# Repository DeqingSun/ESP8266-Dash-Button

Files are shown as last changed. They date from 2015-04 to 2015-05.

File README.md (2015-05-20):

# ESP8266 Dash Button

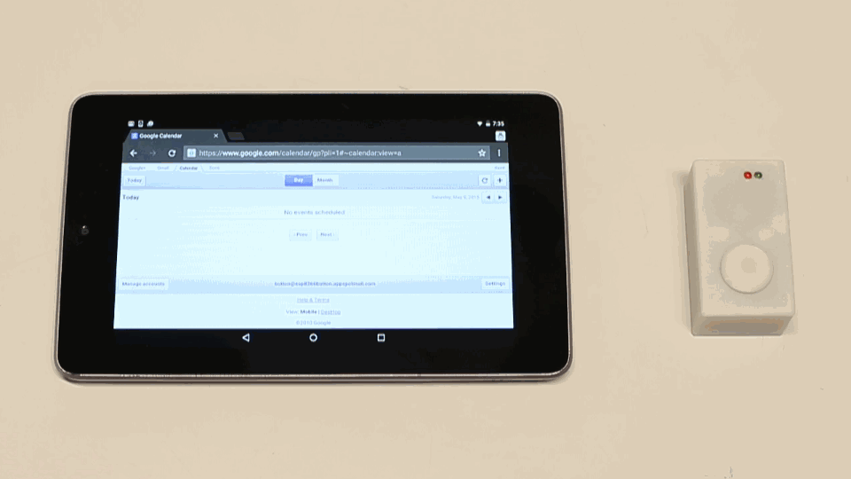
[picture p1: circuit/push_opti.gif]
full


This is a small box with only one button. Every time you push the button. It will connect to WiFi and access an URL.

WiFi SSID and Password can be configured through ESP-TOUCH protocol and the URL can be changed by UDP packet. Two LEDs on it's case shows status of module and circuit.

## Internal Structure

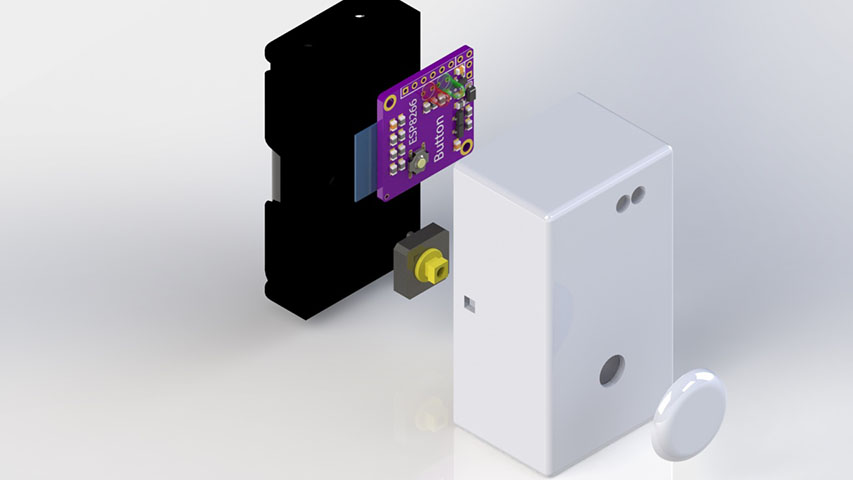
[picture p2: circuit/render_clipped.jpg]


This button consists of following parts: Two AA batteries and battery holder, ESP8266 module and circuit, a big button for better experience, case, button cover. 

## How it works

When button is pressed, the circuit powers ESP8266 module and the module will connect to WiFi with SSID and password in flash memory. Once Wifi connection is established, this button will request a certain URL in flash memory and turn itself off to save power.

## How to config WiFi network and URL

There is an minimal Android app in this repo that can do configuration wirelessly.

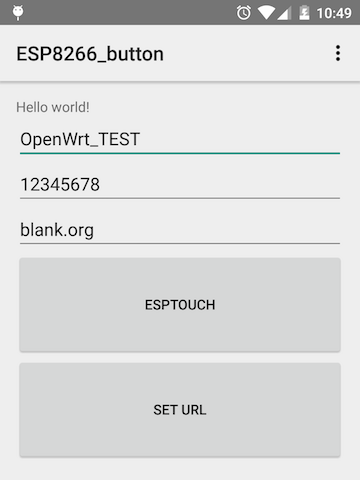
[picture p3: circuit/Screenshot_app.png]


The app is a barely working one and it lacks advanced features for now. However it does work. You can hold button on ESP8266 board for 5 seconds and it will enter ESP-TOUCH mode. The Android code is a bit messy because they are decompiled from a obfuscated APK file. 

You can connect your phone to target WiFi network, fill textbox with SSID and password and press "ESPTouch", then the app will encode SSID and password in length of UDP packets and broadcast packets to all devices. If ESP8266 decodes WiFi information successfully, it will broadcast a UDP packet back to your phone to end pairing process and listen UDP packets for URL. You can enter URL into third textbox and press "SET URL" to finish setting process.

If you want to change the URL only, press button once when it is in ESP-Touch mode.

## How to make one

You can use the gerber files in this repo or you can order PCB with [OSH Park](https://oshpark.com/shared_projects/X8mGIjUE) directly.

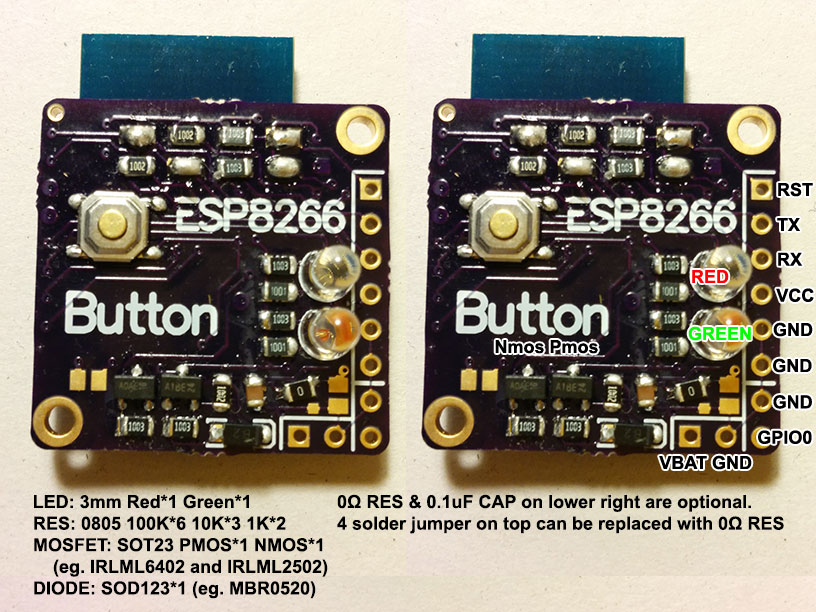
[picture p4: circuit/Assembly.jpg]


After you solder all parts and ESP-12 module, you can either compile the source code on your own or use the pre-compiled bin files. 

## How to do more things with IFTTT

Currently IFTTT can not be triggered with a HTTP request. So I created a App Engine app to send a Email to IFTTT. The app can print all email it received in log file so you can create account with App Engine Email Address.

Here is an example of add Google Calendar entry with button.

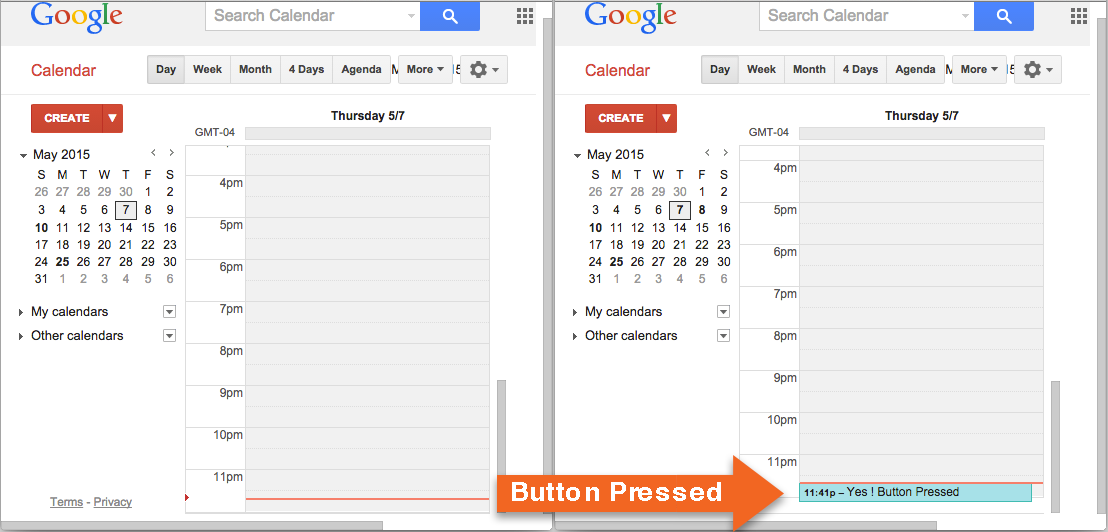
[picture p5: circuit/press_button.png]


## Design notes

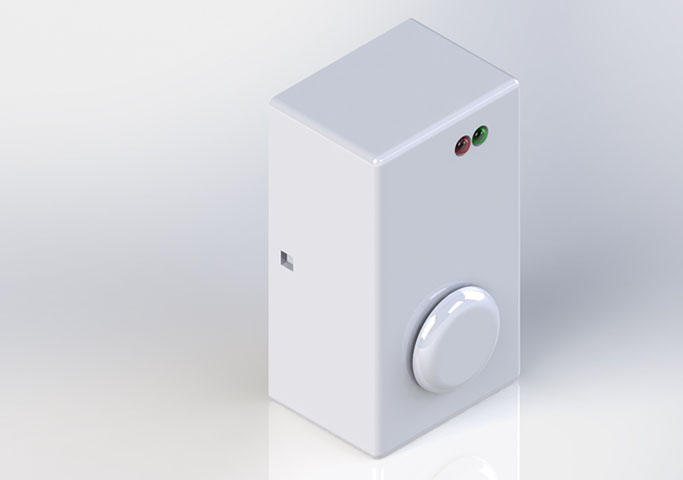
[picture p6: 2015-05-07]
circuit/render_full_clipped.jpg

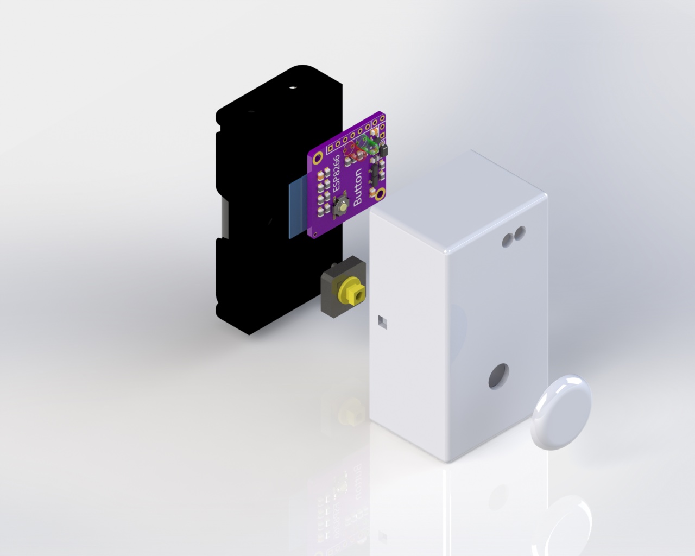
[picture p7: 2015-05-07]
circuit/render.jpg

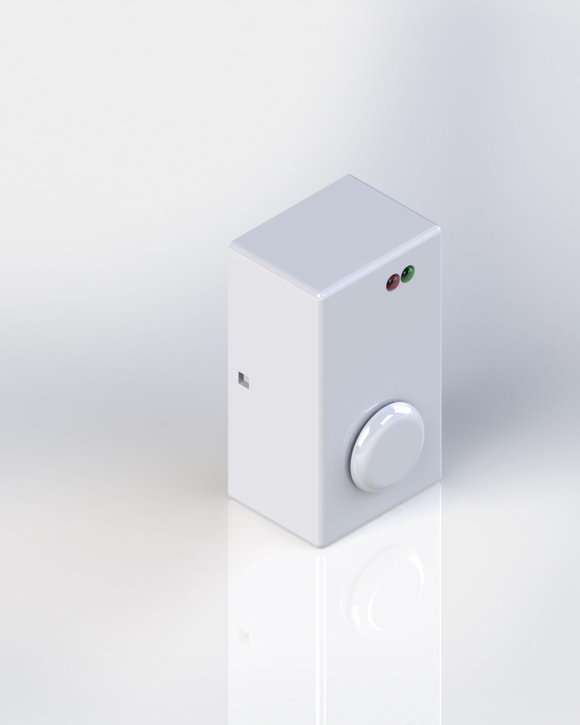
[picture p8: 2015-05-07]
circuit/render_full.jpg

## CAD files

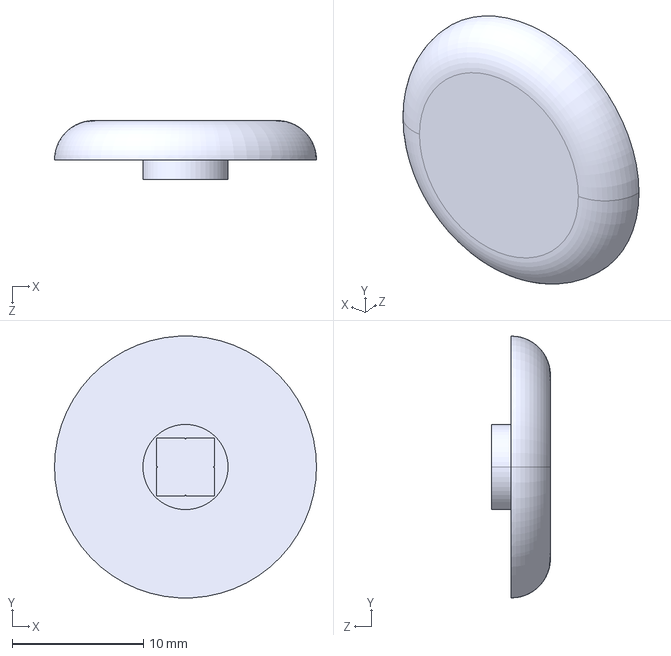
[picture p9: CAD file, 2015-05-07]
circuit/step/button_cap.STEP
20.0 x 20.0 x 4.50 mm

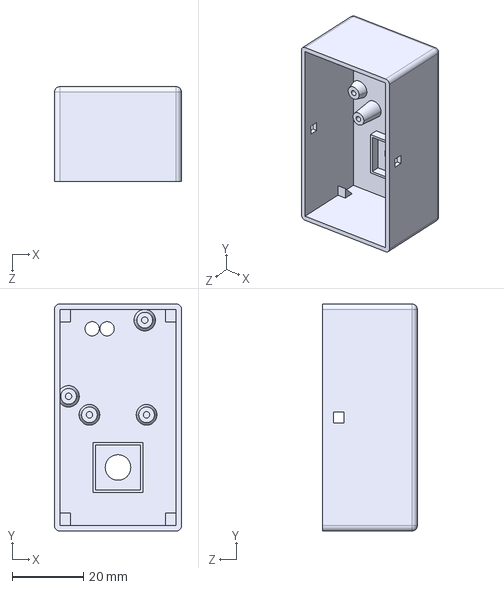
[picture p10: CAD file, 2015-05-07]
circuit/step/case.STEP
35.6 x 63.6 x 26.5 mm

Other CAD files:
circuit/3D print stl/button_cap.STL
circuit/3D print stl/case.STL

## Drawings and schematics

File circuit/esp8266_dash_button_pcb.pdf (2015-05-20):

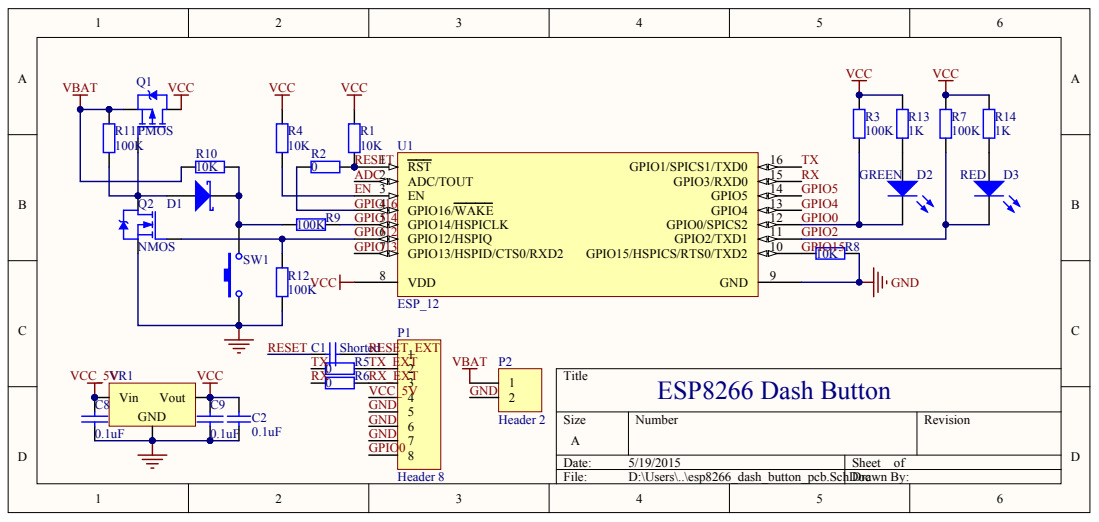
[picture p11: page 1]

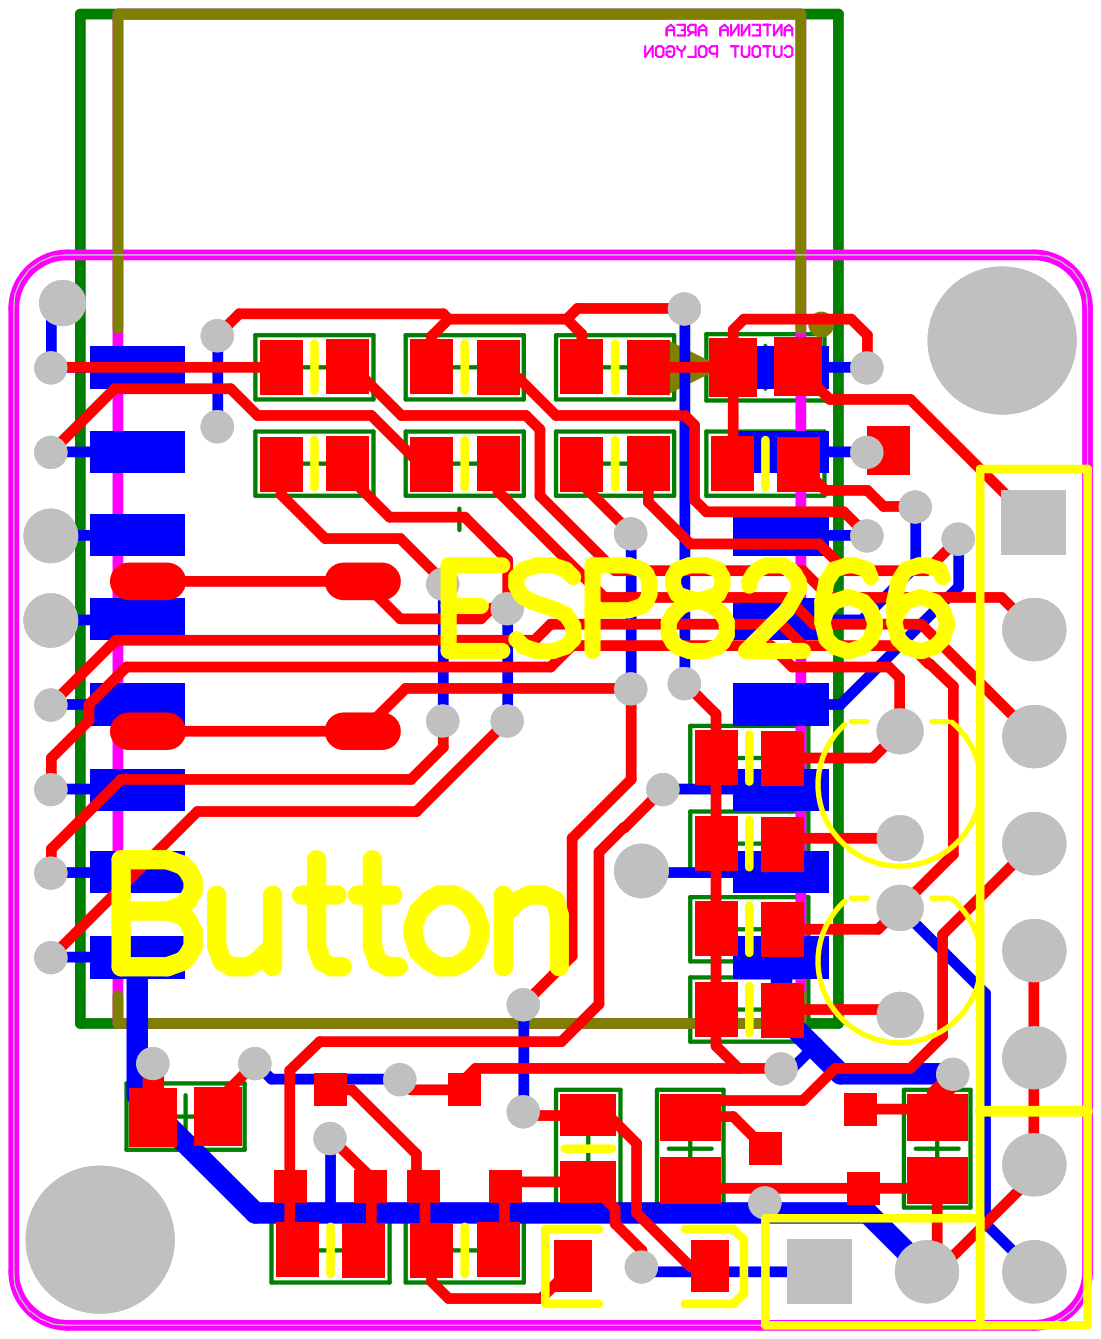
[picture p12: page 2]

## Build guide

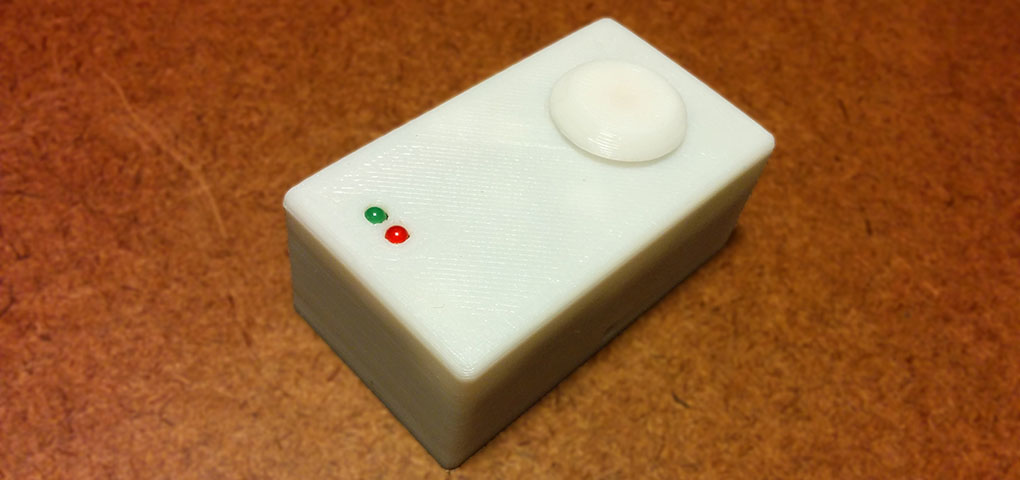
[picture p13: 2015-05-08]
circuit/img_assembled_crop.jpg

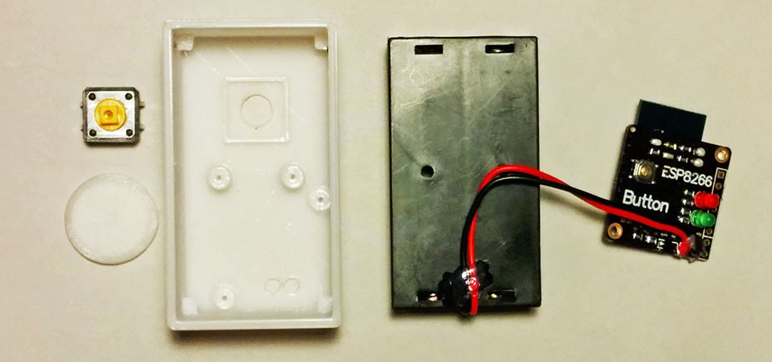
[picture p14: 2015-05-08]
circuit/img_disassembled_crop.jpg

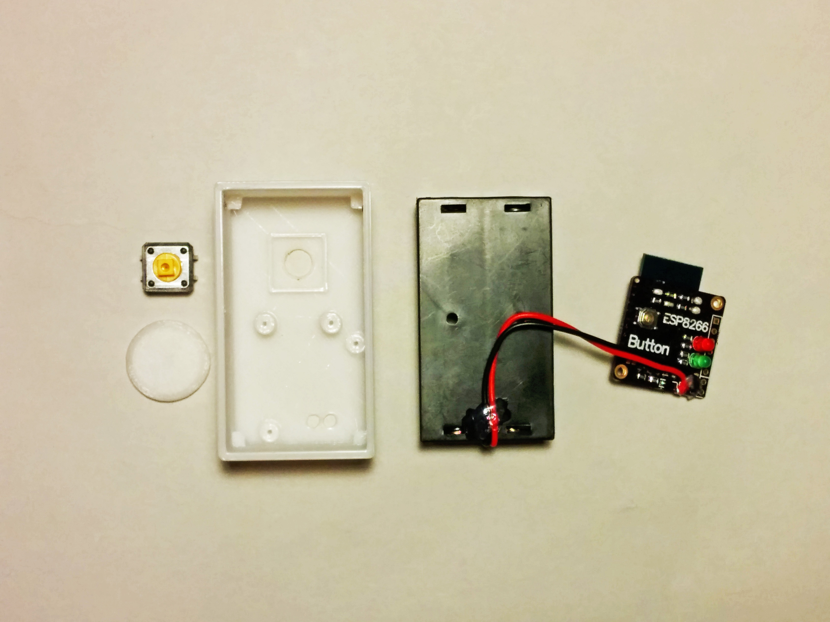
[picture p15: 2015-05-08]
circuit/img_disassembled.jpg

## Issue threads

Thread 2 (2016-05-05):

PSB Scehmatic file

drasko, 2016-05-05:
Hello,
do you have maybe a PCB schematic file to share (KiCAD ideally)?

DeqingSun, 2016-05-05:
There is pdf.

drasko, 2016-05-05:
Yes, I saw PDF file, but I would like to observe and modify the schematic, and if you could provide .sch it would be great.

Closed 2016-05-05.

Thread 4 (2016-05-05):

How many AA batteries

drasko, 2016-05-05:
How many AA batteries this button takes? Is 3 AA batteries needed, as with 2 AA batteries one can only have 3V and this is insufficient for powering ESP-012?

drasko, 2016-11-21:
Any info on this?

manuel-domke, 2017-01-04:
It works starting from 2,5V so two AA batteries will be fine.
3xAA will reach 4,5V which will proably damage the ESP-12 which only accepts up to 3,6V.

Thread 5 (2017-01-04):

Trouble with the URL

manuel-domke, 2017-01-04:
Hi,

I built this and am able to connect to my router (ESP-Touch config successful).

Now it doesn't do the HTTP Request. Tried using IP adress first, then with a local hostname, both didn't work.
Dont see any request in server logs, LED blinks red twice before power-off. It connects to the wifi and gets an ip (seen from dhcp server log).

I've used the precompiled binary files.

Any ideas on this?
I'd guess it might be a problem with the URLParser, which seems to some crazy stuff in handling IPs and hostnames.

manuel-domke, 2017-01-05:
I've tested an external hostname and it works great.

So it seems the handling of IPs (at least RFC1918) doesn't work and the DNS relies on some external server maybe?

I will try to fix it myself.

manuel-domke, 2017-01-05:
After some testing I found out the problem was in my webserver not serving to the hostname I've used.

Still, connecting to an IP doesn't work.

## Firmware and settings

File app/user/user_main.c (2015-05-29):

/******************************************************************************
 * Copyright 2013-2014 Espressif Systems (Wuxi)
 *
 * FileName: user_main.c
 *
 * Description: entry file of user application
 *
 * Modification history:
 *     2014/1/1, v1.0 create this file.
*******************************************************************************/
#include "ets_sys.h"
#include "osapi.h"
#include "gpio.h"

#include "user_interface.h"
#include "smartconfig.h"

#include "access_spiflash.h"
#include "access_web.h"
#include "url_parser.h"
#include "button_n_phase.h"

extern struct spi_config spi_config_buffer;

#define user_procTaskPrio        0
#define user_procTaskQueueLen    1
static volatile os_timer_t some_timer,check_wifi_timer,start_btn_timer;
os_event_t    user_procTaskQueue[user_procTaskQueueLen];
static void user_procTask(os_event_t *events);
bool flash_data_valid;

void ICACHE_FLASH_ATTR some_timerfunc(void *arg)
{
	if (0){
		if (GPIO_INPUT_GET(14)){
			os_printf("P14 HIGH\n");
		}else{
			os_printf("P14 LOW\n");
		}
		//os_printf("%04X\n",gpio_input_get());
	}	
	
   //os_timer_arm(&some_timer, 1000, 0);
}


void ICACHE_FLASH_ATTR check_wifi_timerfunc(void *arg)
{
	switch(wifi_station_get_connect_status()){
		case STATION_IDLE:
			os_printf("STATION_IDLE, STOP\n");
			change_state(BUTTONSTATE_ERR_WIFI_FAILED);
			wifi_station_disconnect();//Stop trying
			break;
		case STATION_CONNECTING:
			//os_printf("STATION_CONNECTING\n");
			os_timer_arm(&check_wifi_timer, 100, 0);
			break;
		case STATION_WRONG_PASSWORD:
			os_printf("STATION_WRONG_PASSWORD, STOP\n");
			change_state(BUTTONSTATE_ERR_WIFI_FAILED);
			wifi_station_disconnect();//Stop trying
			break;	
		case STATION_NO_AP_FOUND:
			os_printf("STATION_NO_AP_FOUND, STOP\n");
			change_state(BUTTONSTATE_ERR_WIFI_FAILED);
			wifi_station_disconnect();//Stop trying
			break;
		case STATION_CONNECT_FAIL:
			os_printf("STATION_CONNECT_FAIL, STOP\n");
			change_state(BUTTONSTATE_ERR_WIFI_FAILED);
			wifi_station_disconnect();//Stop trying
			break;
		case STATION_GOT_IP:
			os_printf("STATION_GOT_IP\n");
			switch (get_state()){
				case BUTTONSTATE_WIFI_LOOK_FOR_AP_NORMAL:{
						struct ip_info ipConfig;
						wifi_get_ip_info(STATION_IF, &ipConfig);
						if (ipConfig.ip.addr != 0){
							///connect_URL("blank.org");
							//connect_URL("173.192.121.250");
							//connect_URL("4.35.21.158/intl/en/about/");
							//connect_URL("retro.hackaday.com/retro.html");
							connect_URL(spi_config_buffer.target_url);
							
						}else{
							os_printf("IP IS ZERO!\n");
							change_state(BUTTONSTATE_ERR_WIFI_FAILED);
							wifi_station_disconnect();//Stop trying
						}
					}
					break;
				case BUTTONSTATE_WIFI_LOOK_FOR_AP_UDP_SERVER:{
						change_state(BUTTONSTATE_UDP_URL);
						init_udp_server();
					}
					break;
			}
			
			
			break;
	}
	//os_printf("CHECK\n");
}

//Do nothing function
static void ICACHE_FLASH_ATTR
user_procTask(os_event_t *events)
{
    os_delay_us(10);
}

void ICACHE_FLASH_ATTR
smartconfig_done(sc_status status, void *pdata)
{
    switch(status) {
        case SC_STATUS_WAIT:
            os_printf("SC_STATUS_WAIT\n");
            break;
        case SC_STATUS_FIND_CHANNEL:
            os_printf("SC_STATUS_FIND_CHANNEL\n");
            break;
        case SC_STATUS_GETTING_SSID_PSWD:
            os_printf("SC_STATUS_GETTING_SSID_PSWD\n");
            break;
        case SC_STATUS_LINK:
            os_printf("SC_STATUS_LINK\n");
            struct station_config *sta_conf = pdata;
			
			change_state(BUTTONSTATE_WIFI_LOOK_FOR_AP_UDP_SERVER);
			os_memcpy(&spi_config_buffer.config, sta_conf, sizeof(struct station_config));
	
			if(!writeSpiSetting()) os_printf("SPI write ERR\n");

			wifi_station_set_config(sta_conf);
			wifi_station_disconnect();
			wifi_station_connect();
			os_timer_arm(&check_wifi_timer, 100, 0);
            break;
        case SC_STATUS_LINK_OVER:
            os_printf("SC_STATUS_LINK_OVER\n");
            smartconfig_stop();
            break;
    }
	if (status==SC_STATUS_WAIT || status==SC_STATUS_FIND_CHANNEL){
		change_state(BUTTONSTATE_ESPTOUCH);
	}else if (status==SC_STATUS_GETTING_SSID_PSWD){
		change_state(BUTTONSTATE_ESPTOUCH_SSID_GOT);
	}		
}

void ICACHE_FLASH_ATTR
startUDPserver(void){
	smartconfig_stop();	
	wifi_station_connect();
	os_timer_arm(&check_wifi_timer, 100, 0);
}

void ICACHE_FLASH_ATTR start_btn_timerfunc(void *arg){
    static button_hold_counter=0;
	if (GPIO_INPUT_GET(14)){
		os_printf("HOLD BTN: %d\n",button_hold_counter*50);
		if (button_hold_counter*50<2000){
			if (flash_data_valid){
				os_printf("Ready to rock\n");
				os_printf("SSID: %s\n",spi_config_buffer.config.ssid);
				os_printf("PASSWORD: %s\n",spi_config_buffer.config.password);
				os_printf("BSSID_set: %d\n",spi_config_buffer.config.bssid_set);
				wifi_set_opmode(STATION_MODE);
				if (! wifi_station_set_config_current(&spi_config_buffer.config)) os_printf("ERR in config\n");	//this shouldn't happen
				if (! wifi_station_set_auto_connect(1)) os_printf("ERR in auto connect\n");	//this shouldn't happen
				os_timer_arm(&check_wifi_timer, 100, 0);
				os_printf("TRY to connect to WIFI\n");
				change_state(BUTTONSTATE_WIFI_LOOK_FOR_AP_NORMAL);
			}else{
				change_state(BUTTONSTATE_ERR_SPIDATA_INVALID);
				wifi_set_opmode(STATION_MODE);
				wifi_station_set_auto_connect(0);	
			}
		}else{
			wifi_set_opmode(STATION_MODE);
			smartconfig_start(SC_TYPE_ESPTOUCH, smartconfig_done, 1);
			change_state(BUTTONSTATE_ESPTOUCH);
		}
	}else{
		button_hold_counter++;
		os_timer_arm(&start_btn_timer, 50, 0);
	}

}

void user_rf_pre_init(void){
}

void user_init(void){
	bool result;

	GPIO_OUTPUT_SET(12, 1);
	PIN_FUNC_SELECT(PERIPHS_IO_MUX_MTDI_U, FUNC_GPIO12);	//hold power on
	
	system_timer_reinit();
    os_printf("SDK version:%s\n", system_get_sdk_version());
	change_state(BUTTONSTATE_BOOT);
	register_button_Callback(startUDPserver);
	
	PIN_FUNC_SELECT(PERIPHS_IO_MUX_MTMS_U, FUNC_GPIO14);
	GPIO_DIS_OUTPUT(14);	//Set GPIO14 to Input
	PIN_PULLUP_DIS(PERIPHS_IO_MUX_MTMS_U);	//internal pull up will affec circuit
	//PIN_PULLDWN_DIS(PERIPHS_IO_MUX_MTMS_U);
	//PIN_PULLDWN_EN(PERIPHS_IO_MUX_MTMS_U);
	
	ETS_GPIO_INTR_DISABLE(); // Disable gpio interrupts
	ETS_GPIO_INTR_ATTACH(button_intr_handler, 14); // GPIO14 interrupt handler
	GPIO_REG_WRITE(GPIO_STATUS_W1TC_ADDRESS, BIT(12)); // Clear GPIO14 status
	gpio_pin_intr_state_set(GPIO_ID_PIN(14), GPIO_PIN_INTR_ANYEDGE); // Interrupt on any GPIO14 edge
	ETS_GPIO_INTR_ENABLE(); // Enable gpio interrupts
	
	os_timer_disarm(&some_timer);
    os_timer_setfn(&some_timer, (os_timer_func_t *)some_timerfunc, NULL);
	os_timer_disarm(&check_wifi_timer);
    os_timer_setfn(&check_wifi_timer, (os_timer_func_t *)check_wifi_timerfunc, NULL);
	os_timer_disarm(&start_btn_timer);
    os_timer_setfn(&start_btn_timer, (os_timer_func_t *)start_btn_timerfunc, NULL);
	
	flash_data_valid=readAndCheckSpiSetting();
	//check button;
	os_timer_arm(&start_btn_timer, 1, 0);

	
/*	os_timer_disarm(&some_timer);
    os_timer_setfn(&some_timer, (os_timer_func_t *)some_timerfunc, NULL);
	os_timer_arm(&some_timer, 1000, 0);*/
	//system_os_task(user_procTask, user_procTaskPrio,user_procTaskQueue, user_procTaskQueueLen);
//	system_os_post(user_procTaskPrio, 0, 0 );
}

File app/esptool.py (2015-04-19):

#!/usr/bin/env python
#
# ESP8266 ROM Bootloader Utility
# https://github.com/themadinventor/esptool
#
# Copyright (C) 2014 Fredrik Ahlberg
#
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
import sys
import struct
import serial
import math
import time
import argparse
import os
import subprocess

class ESPROM:

    # These are the currently known commands supported by the ROM
    ESP_FLASH_BEGIN = 0x02
    ESP_FLASH_DATA  = 0x03
    ESP_FLASH_END   = 0x04
    ESP_MEM_BEGIN   = 0x05
    ESP_MEM_END     = 0x06
    ESP_MEM_DATA    = 0x07
    ESP_SYNC        = 0x08
    ESP_WRITE_REG   = 0x09
    ESP_READ_REG    = 0x0a

    # Maximum block sized for RAM and Flash writes, respectively.
    ESP_RAM_BLOCK   = 0x1800
    ESP_FLASH_BLOCK = 0x400

    # Default baudrate. The ROM auto-bauds, so we can use more or less whatever we want.
    ESP_ROM_BAUD    = 921600

    # First byte of the application image
    ESP_IMAGE_MAGIC = 0xe9

    # Initial state for the checksum routine
    ESP_CHECKSUM_MAGIC = 0xef

    # OTP ROM addresses
    ESP_OTP_MAC0    = 0x3ff00050
    ESP_OTP_MAC1    = 0x3ff00054

    # Sflash stub: an assembly routine to read from spi flash and send to host
    SFLASH_STUB     = "\x80\x3c\x00\x40\x1c\x4b\x00\x40\x21\x11\x00\x40\x00\x80" \
            "\xfe\x3f\xc1\xfb\xff\xd1\xf8\xff\x2d\x0d\x31\xfd\xff\x41\xf7\xff\x4a" \
            "\xdd\x51\xf9\xff\xc0\x05\x00\x21\xf9\xff\x31\xf3\xff\x41\xf5\xff\xc0" \
            "\x04\x00\x0b\xcc\x56\xec\xfd\x06\xff\xff\x00\x00"

    def __init__(self, port = 0, baud = ESP_ROM_BAUD):
        self._port = serial.Serial(port, baud)

    """ Read bytes from the serial port while performing SLIP unescaping """
    def read(self, length = 1):
        b = ''
        while len(b) < length:
            c = self._port.read(1)
            if c == '\xdb':
                c = self._port.read(1)
                if c == '\xdc':
                    b = b + '\xc0'
                elif c == '\xdd':
                    b = b + '\xdb'
                else:
                    raise Exception('Invalid SLIP escape')
            else:
                b = b + c
        return b

    """ Write bytes to the serial port while performing SLIP escaping """
    def write(self, packet):
        buf = '\xc0'+(packet.replace('\xdb','\xdb\xdd').replace('\xc0','\xdb\xdc'))+'\xc0'
        self._port.write(buf)

    """ Calculate checksum of a blob, as it is defined by the ROM """
    @staticmethod
    def checksum(data, state = ESP_CHECKSUM_MAGIC):
        for b in data:
            state ^= ord(b)
        return state

    """ Send a request and read the response """
    def command(self, op = None, data = None, chk = 0):
        if op:
            # Construct and send request
            pkt = struct.pack('<BBHI', 0x00, op, len(data), chk) + data
            self.write(pkt)

        # Read header of response and parse
        if self._port.read(1) != '\xc0':
            raise Exception('Invalid head of packet')
        hdr = self.read(8)
        (resp, op_ret, len_ret, val) = struct.unpack('<BBHI', hdr)
        if resp != 0x01 or (op and op_ret != op):
            raise Exception('Invalid response')

        # The variable-length body
        body = self.read(len_ret)

        # Terminating byte
        if self._port.read(1) != chr(0xc0):
            raise Exception('Invalid end of packet')

        return val, body

    """ Perform a connection test """
    def sync(self):
        self.command(ESPROM.ESP_SYNC, '\x07\x07\x12\x20'+32*'\x55')
        for i in xrange(7):
            self.command()

    """ Try connecting repeatedly until successful, or giving up """
    def connect(self):
        print 'Connecting...'

        # RTS = CH_PD (i.e reset)
        # DTR = GPIO0
        self._port.setRTS(True)
        self._port.setDTR(True)
        self._port.setRTS(False)
        time.sleep(0.1)
        self._port.setDTR(False)

        self._port.timeout = 0.5
        for i in xrange(10):
            try:
                self._port.flushInput()
                self._port.flushOutput()
                self.sync()
                self._port.timeout = 5
                return
            except:
                time.sleep(0.1)
        raise Exception('Failed to connect')

    """ Read memory address in target """
    def read_reg(self, addr):
        res = self.command(ESPROM.ESP_READ_REG, struct.pack('<I', addr))
        if res[1] != "\0\0":
            raise Exception('Failed to read target memory')
        return res[0]

    """ Write to memory address in target """
    def write_reg(self, addr, value, mask, delay_us = 0):
        if self.command(ESPROM.ESP_WRITE_REG,
                struct.pack('<IIII', addr, value, mask, delay_us))[1] != "\0\0":
            raise Exception('Failed to write target memory')

    """ Start downloading an application image to RAM """
    def mem_begin(self, size, blocks, blocksize, offset):
        if self.command(ESPROM.ESP_MEM_BEGIN,
                struct.pack('<IIII', size, blocks, blocksize, offset))[1] != "\0\0":
            raise Exception('Failed to enter RAM download mode')

    """ Send a block of an image to RAM """
    def mem_block(self, data, seq):
        if self.command(ESPROM.ESP_MEM_DATA,
                struct.pack('<IIII', len(data), seq, 0, 0)+data, ESPROM.checksum(data))[1] != "\0\0":
            raise Exception('Failed to write to target RAM')

    """ Leave download mode and run the application """
    def mem_finish(self, entrypoint = 0):
        if self.command(ESPROM.ESP_MEM_END,
                struct.pack('<II', int(entrypoint == 0), entrypoint))[1] != "\0\0":
            raise Exception('Failed to leave RAM download mode')

    """ Start downloading to Flash (performs an erase) """
    def flash_begin(self, size, offset):
        old_tmo = self._port.timeout
        num_blocks = (size + ESPROM.ESP_FLASH_BLOCK - 1) / ESPROM.ESP_FLASH_BLOCK
        self._port.timeout = 10
        if self.command(ESPROM.ESP_FLASH_BEGIN,
                struct.pack('<IIII', size, num_blocks, ESPROM.ESP_FLASH_BLOCK, offset))[1] != "\0\0":
            raise Exception('Failed to enter Flash download mode')
        self._port.timeout = old_tmo

    """ Write block to flash """
    def flash_block(self, data, seq):
        if self.command(ESPROM.ESP_FLASH_DATA,
                struct.pack('<IIII', len(data), seq, 0, 0)+data, ESPROM.checksum(data))[1] != "\0\0":
            raise Exception('Failed to write to target Flash')

    """ Leave flash mode and run/reboot """
    def flash_finish(self, reboot = False):
        pkt = struct.pack('<I', int(not reboot))
        if self.command(ESPROM.ESP_FLASH_END, pkt)[1] != "\0\0":
            raise Exception('Failed to leave Flash mode')

    """ Run application code in flash """
    def run(self, reboot = False):
        # Fake flash begin immediately followed by flash end
        self.flash_begin(0, 0)
        self.flash_finish(reboot)
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

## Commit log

2015-04-15 start from blink LED
2015-04-15 adc functional at 24K
    Horray
2015-04-19 print if successful
2015-04-20 functional button
    GPIO2 and 0 can not be hold on start up.
2015-04-21 add button interrupt with debonce
2015-04-22 prepare another async task for setting URL to device
2015-04-23 button leaves ESP touch
2015-04-23 add button to enter UDP
2015-04-24 Blink LED
2015-04-24 add led for ESP Touch and UDP
2015-04-27 basic button response
2015-04-27 relay web access to email to ifttt
2015-05-06 add led for invalid data
2015-05-06 mosfet control OK
2015-05-06 functional button!
2015-05-07 add 3d files
    [button_cap.STEP, button_cap.STL, case.STEP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]
2015-05-07 add circuit and render
2015-05-13 update LED flash according to ESPTOUCH status
2015-05-20 update circuit

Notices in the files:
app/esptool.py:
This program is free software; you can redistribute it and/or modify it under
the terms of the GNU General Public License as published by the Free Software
